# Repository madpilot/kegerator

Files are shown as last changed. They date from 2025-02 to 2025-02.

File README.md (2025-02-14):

# Replacement Control Board for the Keg Master Series 3 (Model: BC168)

I acquired a Keg Master Series 3 kegerator a while ago. While it's a nice fridge, it was not without it's issues.

1. If power was cut, it would revert back to a default temperature (0.4°C degrees if I remember correctly), and displaying fahrenheit (why!). Beyond the obvious issue of it forgetting the set temperature, this was more an issue because:
2. It was running cold. Any lower than 0.4°C and the kegerator is dangerously close to below freezing. I've managed to freeze a keg and numerous bottles.

So, the obvious thing to do was to make a new controller!

This controller has a ESP32, as well as a 128x32 i²c LCD. 

I've replaced the thermistor with a Dallas ds18b20 temperature sensor (in parasitic mode so I can reuse the two-wires), and added a line for a heater relay so the board can be reused for a fermenter.

The front buttons are wired up as well. The esphome firmware I use switches out the "unit" button with a on/off button.

## Example esphome configuration

```yaml
esphome:
  name: kegerator
  
esp32:
  board: esp32-s2-saola-1

i2c:
  sda: GPIO16
  scl: GPIO15

font:
  - file: "gfonts://Roboto"
    id: font_large
    size: 18
  - file: "gfonts://Roboto"
    id: font_small
    size: 8

display:
  - platform: ssd1306_i2c
    model: "SSD1306 128x32"
    lambda: |-
      float current_temperature = id(kegerator_pid).current_temperature;
      float target_temperature = id(kegerator_pid).target_temperature;
      
      if(id(kegerator_pid).mode == CLIMATE_MODE_COOL) {
        if(!std::isnan(current_temperature)) {
          it.printf(64, 0, id(font_large), TextAlign::TOP_CENTER, "%.1f°C", current_temperature);
        } else {
          it.printf(64, 0, id(font_large), TextAlign::TOP_CENTER, "--°C");
        }
      } else {
          it.printf(64, 0, id(font_large), TextAlign::TOP_CENTER, "Off");
      } 

      if(!std::isnan(target_temperature)) {
        it.printf(64, 32, id(font_small), TextAlign::BOTTOM_CENTER, "%.1f°C", target_temperature);
      } else {
        it.printf(64, 32, id(font_small), TextAlign::BOTTOM_CENTER, "--°C");
      }
      
one_wire:
  - platform: gpio
    pin: GPIO14

sensor:
  - platform: dallas_temp
    id: temperature
    name: "Temperature"
    update_interval: 1s
    unit_of_measurement: "°C"
    device_class: "temperature"
    state_class: "measurement"
    accuracy_decimals: 1
    filters:
      - exponential_moving_average:
          alpha: 0.8
          send_every: 30

binary_sensor:
  - platform: gpio
    id: btn_temp_up
    pin:
      number: GPIO21
      inverted: true
      mode:
          input: true
          pullup: true
    filters:
       autorepeat:
        - delay: 1s
          time_off: 100ms
          time_on: 100ms

    on_click:
      lambda: |-
        float target_temperature = id(kegerator_pid).target_temperature;
        auto call = id(kegerator_pid).make_call();
        call.set_target_temperature(target_temperature + 0.1);
        call.perform();
 
  - platform: gpio
    id: btn_temp_down
    pin: 
      number: GPIO20
      inverted: true
      mode:
          input: true
          pullup: true
    filters:
       autorepeat:
        - delay: 1s
          time_off: 100ms
          time_on: 100ms
    on_click:
      lambda: |-
        float target_temperature = id(kegerator_pid).target_temperature;
        auto call = id(kegerator_pid).make_call();
        call.set_target_temperature(target_temperature - 0.1);
        call.perform();

  - platform: gpio
    id: btn_units
    pin: 
      number: GPIO19     
      inverted: true
      mode:
          input: true
          pullup: true
    on_click:
      then:
        lambda: |-
          auto call = id(kegerator_pid).make_call();
          if(id(kegerator_pid).mode == CLIMATE_MODE_COOL) {
            call.set_mode("OFF");
          } else {
            call.set_mode("COOL");
          }
          call.perform();

button:
  - platform: template
    name: "Kegerator PID Climate Autotune"
    on_press:
      - climate.pid.autotune: kegerator_pid

output:
  id: compressor
  platform: slow_pwm
  pin: GPIO18
  period: 1200s

climate:
  - platform: pid
    id: kegerator_pid
    name: "Kegerator"
    sensor: temperature
    default_target_temperature: 7°C
    cool_output: compressor
    visual:
      min_temperature: -7
      max_temperature: 32
      temperature_step: 0.1
    control_parameters:
      kp: 0.19714
      ki: 0.00028
      kd: 34.89431

logger:

api:
  password: ""

ota:
  - platform: esphome
    password: ""

wifi:
  ssid: WIFI_SSID
  password: WIFI_PASSWORD

  ap:
    ssid: "Kegerator"
    password: ""

captive_portal:
```

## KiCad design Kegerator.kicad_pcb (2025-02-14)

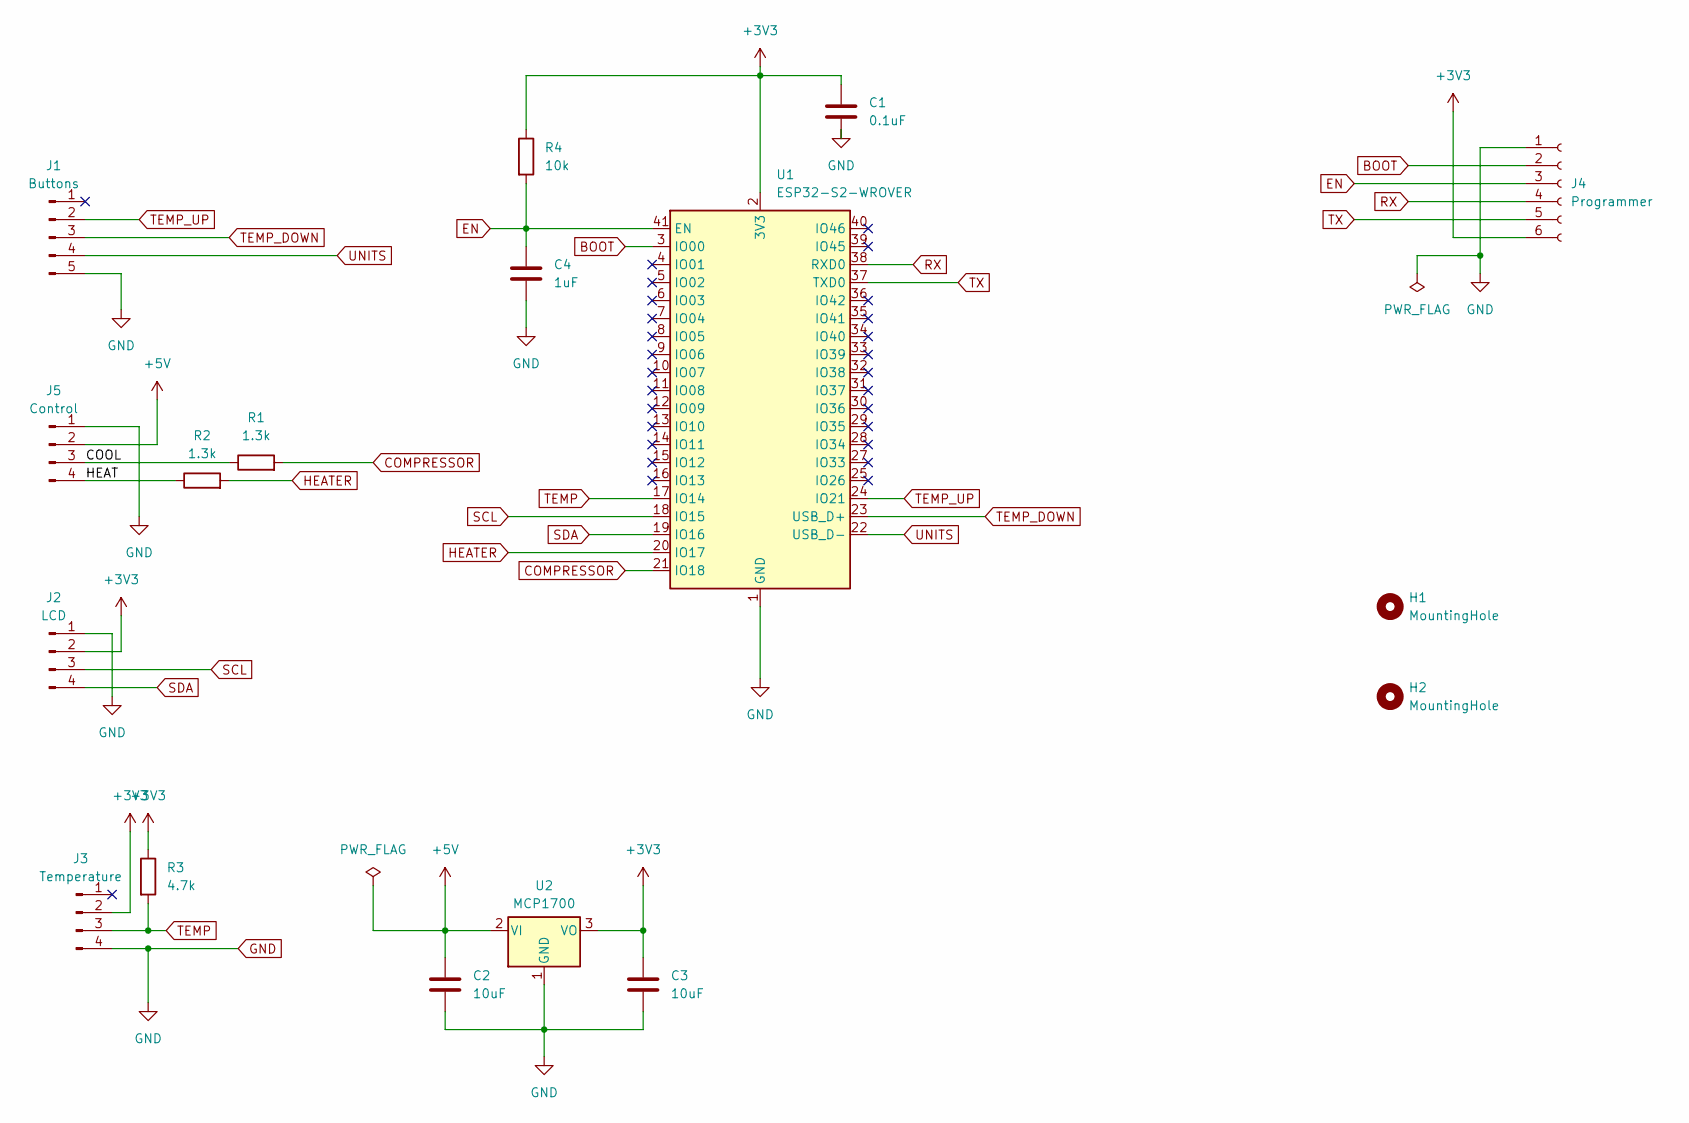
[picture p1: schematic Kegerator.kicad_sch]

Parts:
C1: 0.1uF; C_0805_2012Metric
C2, C3: 10uF; C_0805_2012Metric
C4: 1uF; C_0805_2012Metric
H1, H2: MountingHole; MountingHole_3mm
J1: Buttons; PinHeader_1x05_P2.54mm_Vertical
J2: LCD; 0.91 Inch OLED Module 128X32
J3: Temperature; JST_PH_B4B-PH-K_1x04_P2.00mm_Vertical
J4: Programmer; PinHeader_1x06_P2.54mm_Vertical
J5: Control; JST_XH_B4B-XH-A_1x04_P2.50mm_Vertical
R1, R2: 1.3k; R_0805_2012Metric
R3: 4.7k; R_0805_2012Metric
R4: 10k; R_0805_2012Metric
U1: ESP32-S2-WROVER
U2: MCP1700; SOT-89-3

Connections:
+3V3: C1.1, C3.1, J2.2, J3.2, J4.6, R3.1, R4.1, U1.2 (3V3), U2.3 (VO)
+5V: C2.1, J5.2, U2.2 (VI)
/COOL: J5.3, R1.1
/HEAT: J5.4, R2.1
BOOT: J4.2, U1.3 (IO00)
COMPRESSOR: R1.2, U1.21 (IO18)
EN: C4.1, J4.3, R4.2, U1.41 (EN)
GND: C1.2, C2.2, C3.2, C4.2, J1.5, J2.1, J3.4, J4.1, J5.1, U1.1 (GND), U1.26 (GND), U1.42 (GND), U1.43 (GND), U2.1 (GND)
HEATER: R2.2, U1.20 (IO17)
RX: J4.4, U1.38 (RXD0)
SCL: J2.3, U1.18 (IO15)
SDA: J2.4, U1.19 (IO16)
TEMP: J3.3, R3.2, U1.17 (IO14)
TEMP_DOWN: J1.3, U1.23 (USB_D+)
TEMP_UP: J1.2, U1.24 (IO21)
TX: J4.5, U1.37 (TXD0)
UNITS: J1.4, U1.22 (USB_D-)

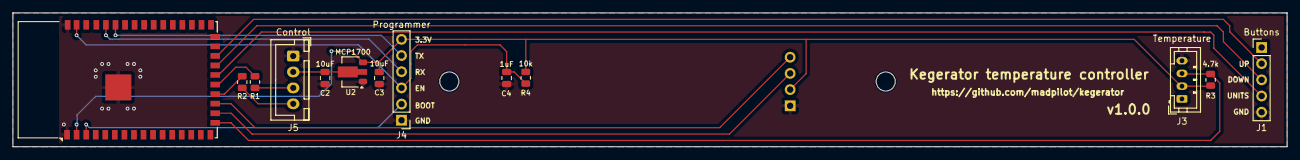
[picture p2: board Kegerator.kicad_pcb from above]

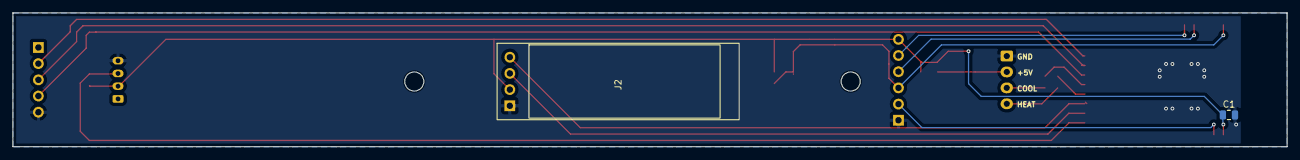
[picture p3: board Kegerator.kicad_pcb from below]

Board: 2 copper layers, 200.0 x 21.0 mm, 17 parts (2 on the bottom side), 17 nets.

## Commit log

2025-01-20 Allowing the temperature sensor to be able to be both really powered or parasitic power
    [Kegerator.kicad_pcb, Kegerator.kicad_sch]
2025-01-20 Few cleanups
    [Kegerator.kicad_pcb]
2025-01-23 Adjusting LCD and screw positions
    [Kegerator.kicad_pcb]
2025-01-23 Final adjustments to screw layouts and cleaning up some tracks
    [Kegerator.kicad_pcb]
2025-01-27 Adding gerber directory
2025-01-27 Add notes about the units button
2025-02-14 STop using GPIO26
    [Kegerator.kicad_pcb, Kegerator.kicad_sch]
2025-02-14 Updaing README with the correct sample code
